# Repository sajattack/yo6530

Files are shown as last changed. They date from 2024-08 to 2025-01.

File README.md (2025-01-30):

yo6530 running a KIM-1 replica

build status (https://builds.sr.ht/~sajattack/yo6530?)

## Dependencies
- FPGA Toolchain: https://github.com/YosysHQ/oss-cad-suite-build
- Simulator: https://verilator.org/guide/latest/install.html
- C++ toolchain: gcc and gnu make
- Trace Viewer: https://gtkwave.sourceforge.net/
- SPI flash programmer: https://www.flashrom.org/
- Linter: https://github.com/chipsalliance/verible
- Hardware research in dwfpy directory uses a Digilent Digital Discovery, python and the dwfpy library to probe and stimulate a MOS6532, for understanding expected behaviour from real hardware

## Target Hardware
https://github.com/daglem/redip-riot

## Programming the board using Raspberry Pi (3B) with flashrom
### Wiring

| Raspi pin name/num  | ReDIP RIOT name/num|
| --- | ---|
| SCK / 23 | SPI_SCLK / 3 |
| MISO / 21 | SPI_SIO1 / 5 |
| MOSI / 19 | SPI_SIO0 / 7 |
| CE0 / 24 | SPI_CS / 1 |
| GPIO25 / 22 | CDONE / 2 |
| 3v3 / 17 | 3v3 / 8 |
| GND / 20 | GND / 6 |
| GPIO24 / 18 | CRESET / 4 |

```sh
make MCS6530_002=1 # build the project
scp build/mcs6530.bin pi@<your-pi's-ip>: # copy the build artifact to the pi for flashing
ssh pi@<your-pi's-ip> # connect to the pi
sudo raspi-config # go into the interfaces menu and enable spi after running this command
pinctrl set 24 op dl # put the board into programming mode by setting creset low
flashrom -p linux_spi:dev=/dev/spidev0.0,spispeed=20000 # if this detects the device, all is good, otherwise check your spi is enabled and your wiring
truncate -s 128K mcs6530.bin # pad the rom to 128K
flashrom -p linux_spi:dev=/dev/spidev0.0,spispeed=20000 -w mcs6530.bin # write the flash
pinctrl set 24 ip pu # exit programming mode by returning creset to input pullup
```

## Building and running the simulation tests
```sh
make MCS6530_002=1 sim
./obj_dir/Vverilator_top # this will throw assertion errors if the tests fail
```
Also you can examine the logic signals output during the test in the Vverilator_top.vcd file using [GTKWave](https://gtkwave.sourceforge.net/)

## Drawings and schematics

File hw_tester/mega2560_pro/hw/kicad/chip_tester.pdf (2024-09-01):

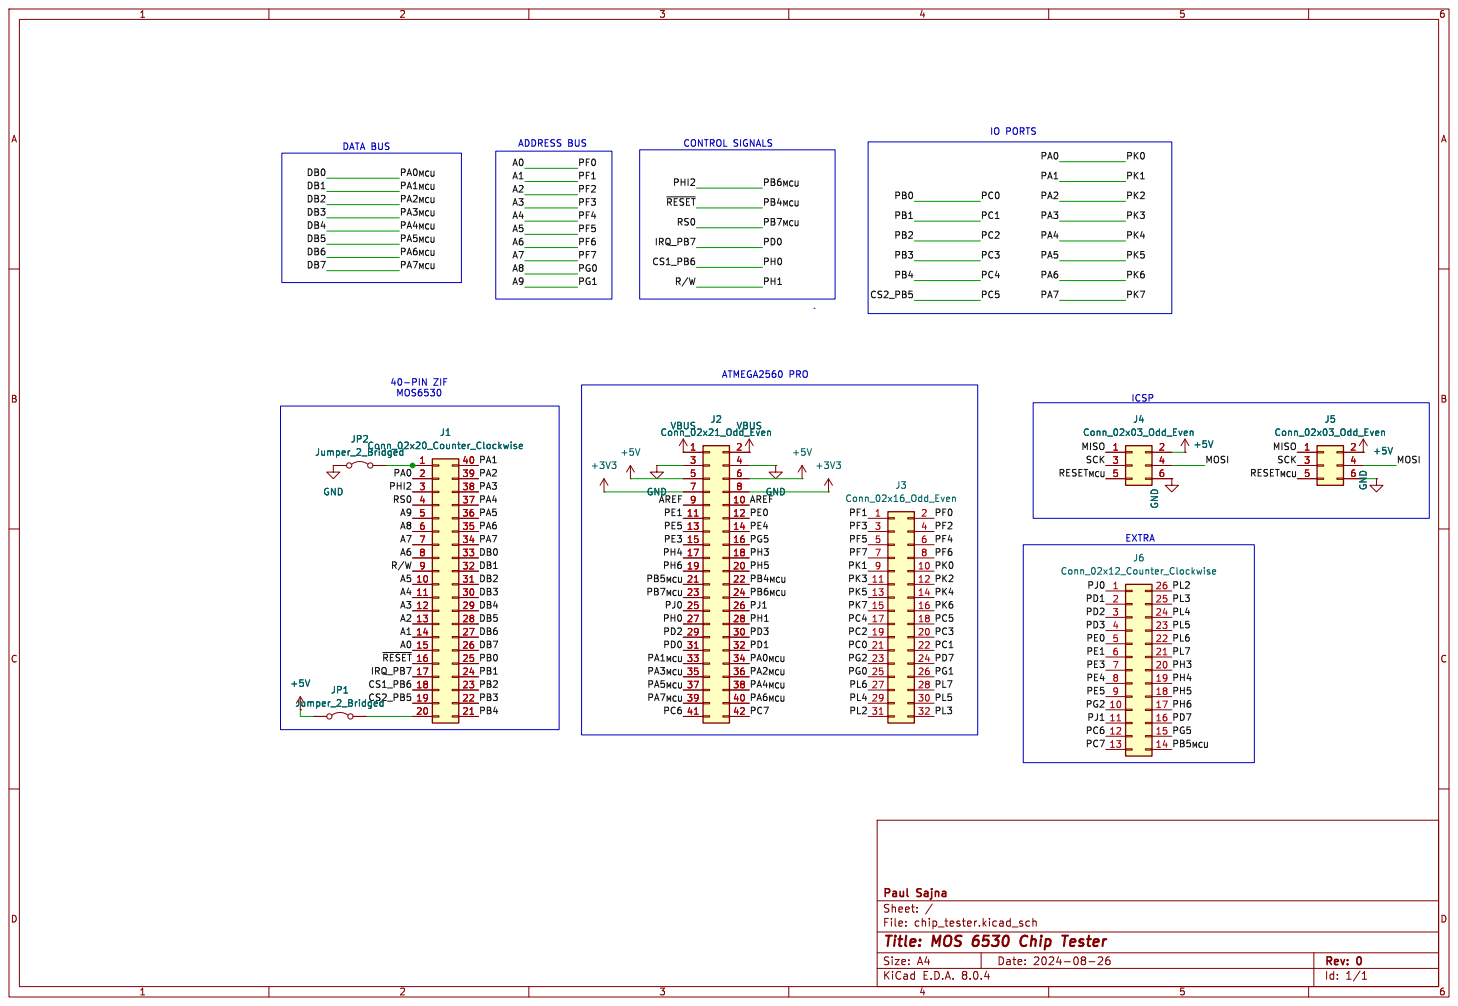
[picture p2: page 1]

IO PORTS CONTROL SIGNALS

Id: 1/1 Title: MOS 6530 Chip Tester File: chip_tester.kicad_sch Sheet: / Paul Sajna

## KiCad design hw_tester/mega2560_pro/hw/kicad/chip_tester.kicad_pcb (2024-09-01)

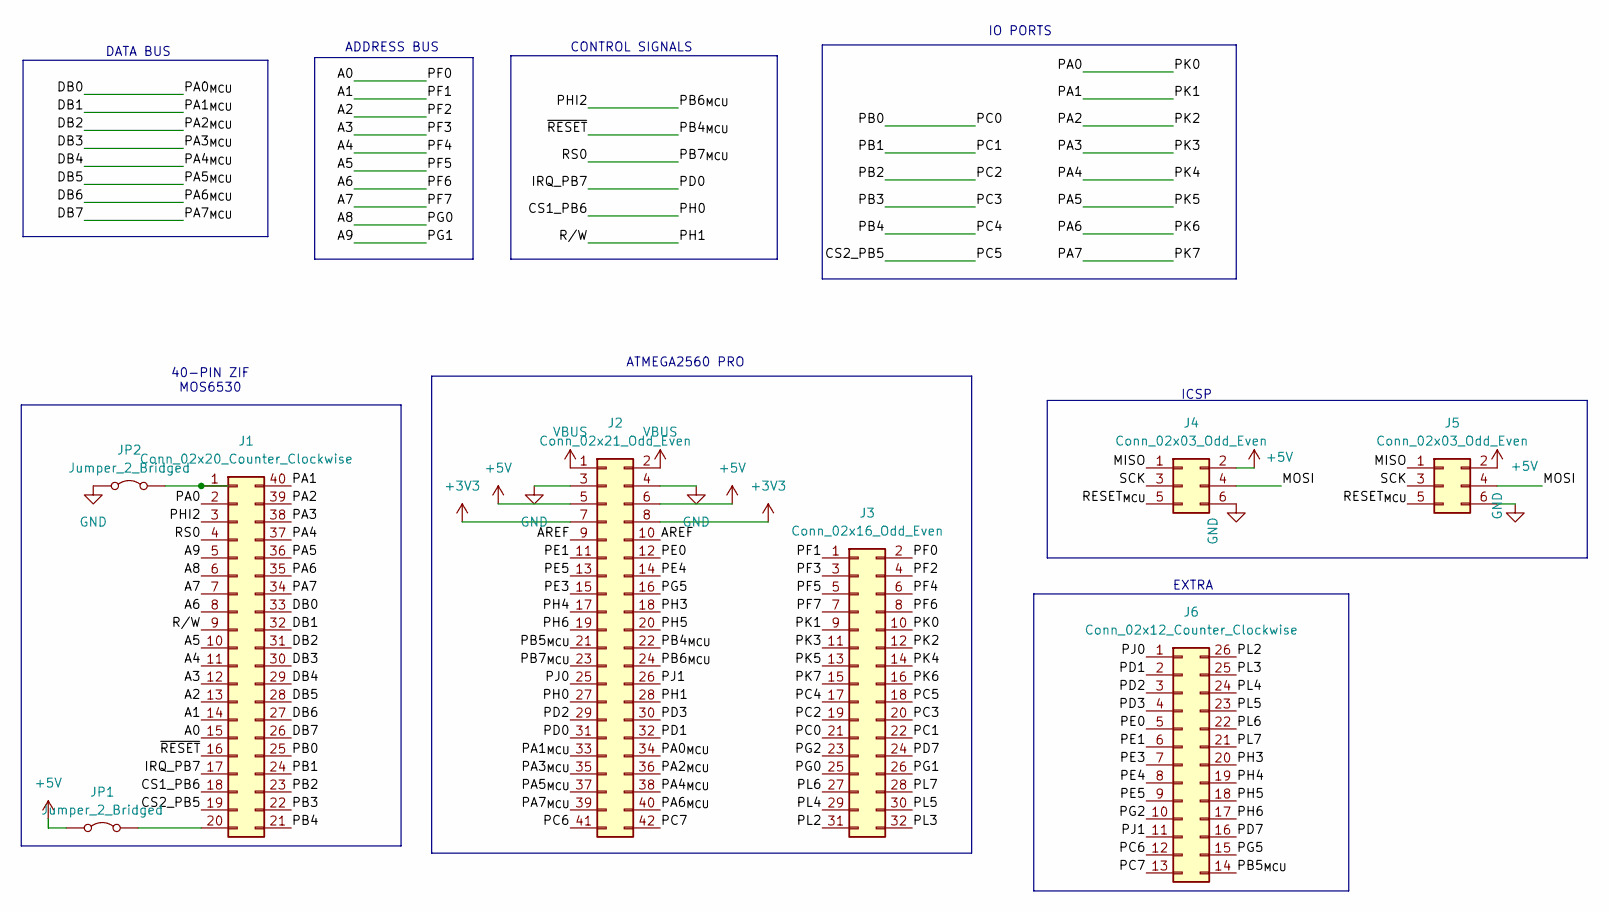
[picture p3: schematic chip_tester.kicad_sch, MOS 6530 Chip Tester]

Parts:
J1: Conn_02x20_Counter_Clockwise; 3M_Textool_240-1288-00-0602J_2x20_P2.54mm
J2: Conn_02x21_Odd_Even; PinHeader_2x21_P2.54mm_Vertical
J3: Conn_02x16_Odd_Even; PinHeader_2x16_P2.54mm_Vertical
J4, J5: Conn_02x03_Odd_Even; PinHeader_2x03_P2.54mm_Vertical
J6: Conn_02x12_Counter_Clockwise; PinHeader_2x13_P2.54mm_Vertical
JP1, JP2: Jumper_2_Bridged; SolderJumper-2_P1.3mm_Bridged_RoundedPad1.0x1.5mm

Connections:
+3V3: J2.7, J2.8
+5V: J2.5, J2.6, J4.2, J5.2, JP1.1 (A)
/A0: J1.15, J3.2
/A1: J1.14, J3.1
/A2: J1.13, J3.4
/A3: J1.12, J3.3
/A4: J1.11, J3.6
/A5: J1.10, J3.5
/A6: J1.8, J3.8
/A7: J1.7, J3.7
/A8: J1.6, J3.25
/A9: J1.5, J3.26
/AREF: J2.9, J2.10
/CS1_PB6: J1.18, J2.27
/CS2_PB5: J1.19, J3.18
/DB0: J1.33, J2.34
/DB1: J1.32, J2.33
/DB2: J1.31, J2.36
/DB3: J1.30, J2.35
/DB4: J1.29, J2.38
/DB5: J1.28, J2.37
/DB6: J1.27, J2.40
/DB7: J1.26, J2.39
/IRQ_PB7: J1.17, J2.31
/MISO: J4.1, J5.1
/MOSI: J4.4, J5.4
/PA0: J1.2, J3.10
/PA1: J1.40, J3.9
/PA2: J1.39, J3.12
/PA3: J1.38, J3.11
/PA4: J1.37, J3.14
/PA5: J1.36, J3.13
/PA6: J1.35, J3.16
/PA7: J1.34, J3.15
/PB0: J1.25, J3.21
/PB1: J1.24, J3.22
/PB2: J1.23, J3.19
/PB3: J1.22, J3.20
/PB4: J1.21, J3.17
/PB4_{MCU}: J1.16, J2.22
/PB5_{MCU}: J2.21, J6.14
/PB6_{MCU}: J1.3, J2.24
/PB7_{MCU}: J1.4, J2.23
/PC6: J2.41, J6.12
/PC7: J2.42, J6.13
/PD1: J2.32, J6.2
/PD2: J2.29, J6.3
/PD3: J2.30, J6.4
/PD7: J3.24, J6.16
/PE0: J2.12, J6.5
/PE1: J2.11, J6.6
/PE3: J2.15, J6.7
/PE4: J2.14, J6.8
/PE5: J2.13, J6.9
/PG2: J3.23, J6.10
/PG5: J2.16, J6.15
/PH1: J1.9, J2.28
/PH3: J2.18, J6.20
/PH4: J2.17, J6.19
/PH5: J2.20, J6.18
/PH6: J2.19, J6.17
/PJ0: J2.25, J6.1
/PJ1: J2.26, J6.11
/PL2: J3.31, J6.26
/PL3: J3.32, J6.25
/PL4: J3.29, J6.24
/PL5: J3.30, J6.23
/PL6: J3.27, J6.22
/PL7: J3.28, J6.21
/RESET_{MCU}: J4.5, J5.5
/SCK: J4.3, J5.3
GND: J2.3, J2.4, J4.6, J5.6, JP2.1 (A)
unnamed: J1.1, JP2.2 (B)
unnamed: J1.20, JP1.2 (B)
VBUS: J2.1, J2.2

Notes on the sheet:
ADDRESS BUS
IO PORTS
ICSP
40-PIN ZIF MOS6530
EXTRA
ATMEGA2560 PRO
DATA BUS
CONTROL SIGNALS

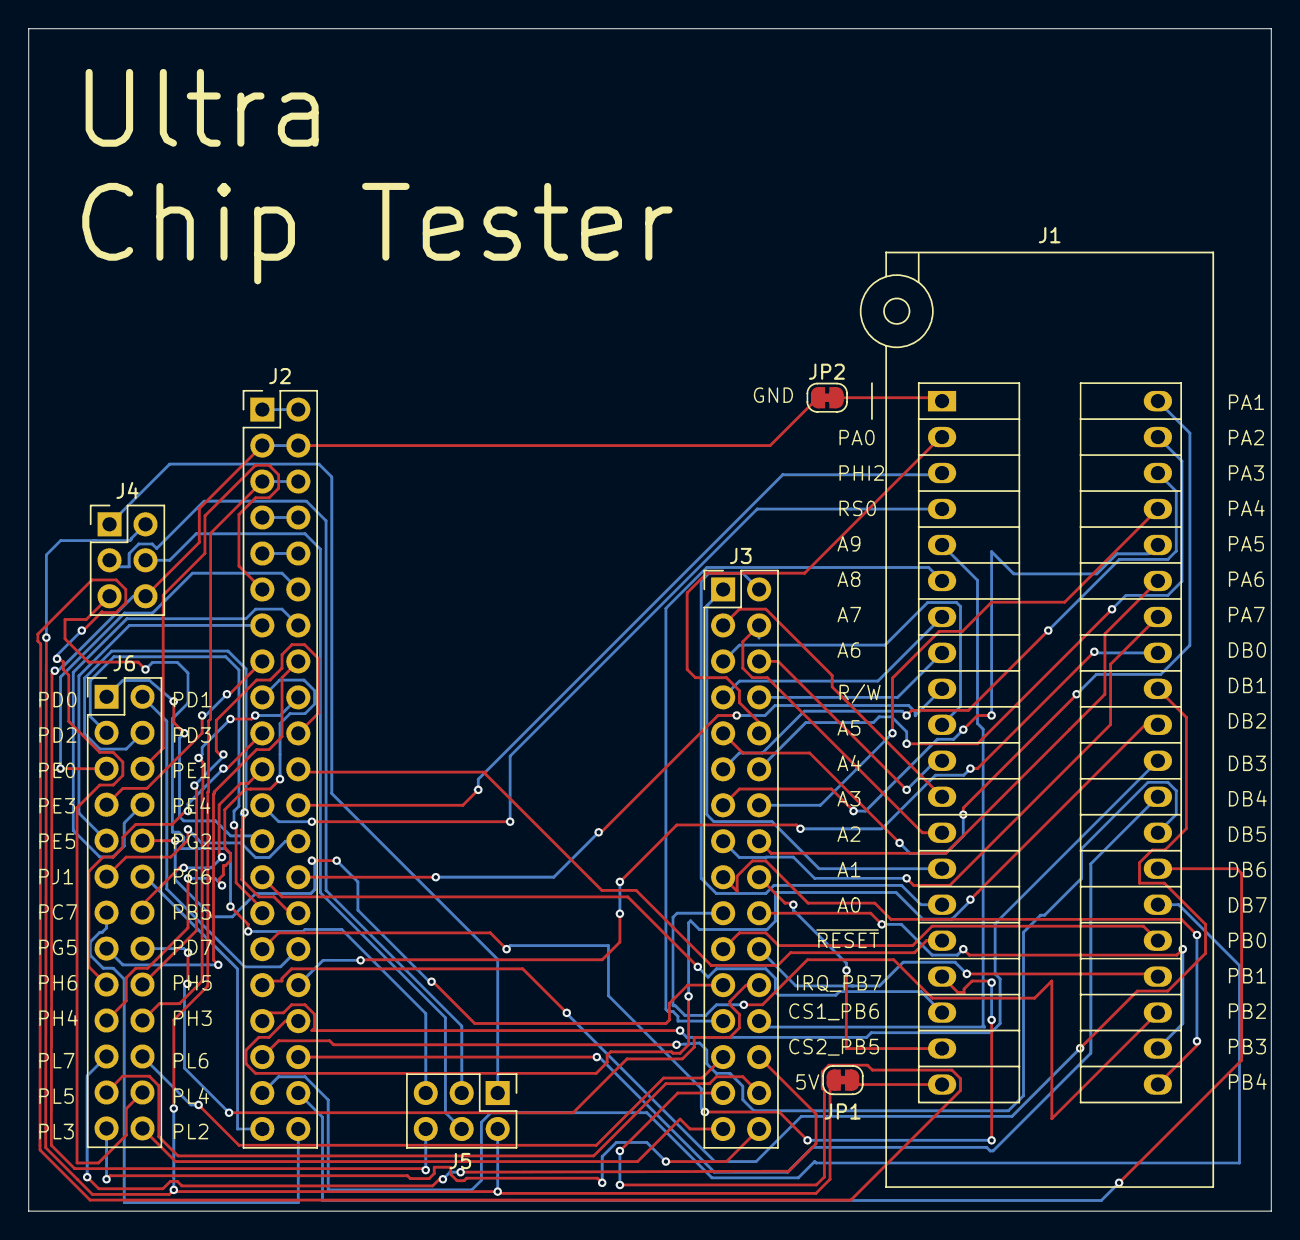
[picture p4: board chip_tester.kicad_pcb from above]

Board: 2 copper layers, 87.8 x 83.5 mm, 8 parts (0 on the bottom side), 75 nets.

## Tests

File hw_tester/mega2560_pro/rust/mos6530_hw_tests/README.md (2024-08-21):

mos6530_hw_tests
================

Rust project for the _Arduino Mega 2560_.

## Build Instructions
1. Install prerequisites as described in the [`avr-hal` README] (`avr-gcc`, `avr-libc`, `avrdude`, [`ravedude`]).

2. Run `cargo build` to build the firmware.

3. Run `cargo run` to flash the firmware to a connected board.  If `ravedude`
   fails to detect your board, check its documentation at
   <https://crates.io/crates/ravedude>.

4. `ravedude` will open a console session after flashing where you can interact
   with the UART console of your board.

[`avr-hal` README]: https://github.com/Rahix/avr-hal#readme
[`ravedude`]: https://crates.io/crates/ravedude

## License
Licensed under either of

 - Apache License, Version 2.0
   ([LICENSE-APACHE](LICENSE-APACHE) or <http://www.apache.org/licenses/LICENSE-2.0>)
 - MIT license
   ([LICENSE-MIT](LICENSE-MIT) or <http://opensource.org/licenses/MIT>)

at your option.

## Contribution
Unless you explicitly state otherwise, any contribution intentionally submitted
for inclusion in the work by you, as defined in the Apache-2.0 license, shall
be dual licensed as above, without any additional terms or conditions.

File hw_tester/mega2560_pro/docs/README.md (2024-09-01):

## Purchase Link
https://www.aliexpress.com/item/1005006102314234.html

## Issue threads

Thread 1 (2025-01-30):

Change ifdefs to verilog module parameters

sajattack, 2025-01-30:
It would be nicer for consumers of this module if we used verilog module parameters instead of defines. Like say someone wanted to make a kim-1 verilog module, they would need to create two wrapper files with different defines for the two different 6530s or something currently. Parameters would make this better.

sajattack, 2025-02-26:
resolved in 3a81e4ac4fda2156d2c24cc2ff9b66108605bdcd

Closed 2025-02-26.

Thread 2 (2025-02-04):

KIM-1 ROMs filler bytes

HansOtten, 2025-02-04:
Not that it will make any functional difference, but the ROM dumps of a real KIM-1 have 00 as filler bytes, not the FF as found in the ROMs generated from assembly source, as you have included here.

I have documented this here: http://retro.hansotten.nl/original-kim-1-roms-reproduced/

Hans

BTW Great work this replacement! Hope some one will sell reDIPs in the future.

sajattack, 2025-02-04:
I appreciate your interest Hans. Your website was very helpful to me during this project. I noticed this actually while I was working on my tester and comparing to real chips. I'll get it corrected. I have a small number of extra reDIP RRIOTs and I would be happy to sell you one or two. Send me an email if you're interested.

HansOtten, 2025-02-05:
Hi Paul,

Nice to hear from you. And breathing life in old damaged KIM-1s with 6530 replacements!

Yes, I love to have some reDIPs. Two would be fine to populate my Eduardo Casino (a good friend of mine, we had some fun recreating the KIM-1 PCB, brilliant work by him).

Let me know what the price is, an shipping cost, paypal is fine.

Greetings!

Hans Otten

Meester van Busselstraat 15

5731 NA Mierlo

The Netherlands

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

HansOtten, 2025-02-05:
Email sent!

Closed 2025-02-07.

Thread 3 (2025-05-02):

Asteroid seems to run too fast (timer issue)

sajattack, 2025-05-02:
Following game seems to instantly kill the player, indicating an issue with my timer code on the RRIOTs:
https://github.com/jefftranter/6502/tree/master/asm/KIM-1/TheFirstBookOfKIM/Games/Asteroid

See video for rough expected speed
https://www.youtube.com/watch?v=xQMCROH3mDc

Closed 2025-05-02.

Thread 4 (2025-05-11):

Improve naming conventions

sajattack, 2025-05-11:
- mixup of DDR/OE
- OE used for function select (use ie timer_select instead)
- maybe try to find a better name for we_n
- also try to fix the `// Data to processor` comments that are blatantly wrong

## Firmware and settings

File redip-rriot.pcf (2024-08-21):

# MOS 6530 RRIOT
# Pin Constraints File for iCE40UP5K-SG48

set_io -nowarn A0      18
set_io -nowarn A1      19
set_io -nowarn A2      20
set_io -nowarn A3      21
set_io -nowarn A4      23
set_io -nowarn A5      27
set_io -nowarn A6      25
set_io -nowarn A7      41
set_io -nowarn A8      40
set_io -nowarn A9      39
set_io -nowarn RS0     28

set_io -nowarn DB0     44
set_io -nowarn DB1     45
set_io -nowarn DB2     46
set_io -nowarn DB3      6
set_io -nowarn DB4      4
set_io -nowarn DB5      3
set_io -nowarn DB6      2
set_io -nowarn DB7     48

set_io -nowarn -pullup 1 -pullup_resistor 6P8K PA0     32
set_io -nowarn -pullup 1 -pullup_resistor 6P8K PA1     34
set_io -nowarn -pullup 1 -pullup_resistor 6P8K PA2     35
set_io -nowarn -pullup 1 -pullup_resistor 6P8K PA3     36
set_io -nowarn -pullup 1 -pullup_resistor 6P8K PA4     37
set_io -nowarn -pullup 1 -pullup_resistor 6P8K PA5     38
set_io -nowarn -pullup 1 -pullup_resistor 6P8K PA6     42
set_io -nowarn -pullup 1 -pullup_resistor 6P8K PA7     43

set_io -nowarn -pullup 1 -pullup_resistor 6P8K PB0     47
set_io -nowarn -pullup 1 -pullup_resistor 6P8K PB1      9
set_io -nowarn -pullup 1 -pullup_resistor 6P8K PB2     10
set_io -nowarn -pullup 1 -pullup_resistor 6P8K PB3     11
set_io -nowarn -pullup 1 -pullup_resistor 6P8K PB4     12
set_io -nowarn -pullup 1 -pullup_resistor 6P8K CS2_PB5 13
set_io -nowarn -pullup 1 -pullup_resistor 6P8K CS1_PB6 14
set_io -nowarn -pullup 1 -pullup_resistor 6P8K IRQ_PB7 15

set_io -nowarn PHI2    31
set_io -nowarn RES     17
set_io -nowarn R_W     26

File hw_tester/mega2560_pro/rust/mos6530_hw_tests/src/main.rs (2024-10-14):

#![no_std]
#![no_main]

#![feature(abi_avr_interrupt)]
#![feature(asm_experimental_arch)]
/// MOS 6530 Chip Tester
///
/// Data bus PA0-PA7
/// Addr bus PF0-PF7 + PG0-1
/// PHI2 PB6
/// RW PH1
/// RS0 PB7
/// RESET PB4
/// IRQ PD0
/// CS1 PH0
/// IO PORTS PC0-5 PK0-7

use panic_serial as _;

panic_serial::impl_panic_handler!(
  // This is the type of the UART port to use for printing the message:
  arduino_hal::usart::Usart<
    arduino_hal::pac::USART0,
    arduino_hal::port::Pin<arduino_hal::port::mode::Input, arduino_hal::hal::port::PE0>,
    arduino_hal::port::Pin<arduino_hal::port::mode::Output, arduino_hal::hal::port::PE1>
  >
);

extern crate alloc;

use alloc::vec::Vec;

use core::{time::Duration, convert::Infallible};

use arduino_hal::{
    Pins,
    Peripherals,
    pac::{
        PORTA,
        PORTB,
        PORTC,
        PORTK,
        PORTF,
        PORTH,
        PORTG,
        PORTD,
        TC1, USART0, EXINT,
        SPI,
    }, hal::{Usart, Atmega, port::{PE0, PE1}}, port::{Pin, mode::{Input, Output}}, clock::MHz16
};

use arduino_hal::hal::spi::{self, Spi, SpiOps};
use spi_flash::Flash;
use embedded_hal::{spi::SpiDevice, spi::SpiBus , digital::OutputPin};
use embedded_hal_bus::spi::ExclusiveDevice;

static ROM_002: [u8; 1024] = *include_bytes!("../../../../../roms/6530-002.bin");
static ROM_003: [u8; 1024] = *include_bytes!("../../../../../roms/6530-003.bin");

#[avr_device::interrupt(atmega2560)]
fn INT0() {
    //let dp = unsafe { arduino_hal::Peripherals::steal() };
    //let pins = arduino_hal::hal::pins!(dp);
    //let mut serial = arduino_hal::hal::usart::Usart0::new(dp.USART0, pins.pe0.into(), pins.pe1.into_output(), arduino_hal::usart::Baudrate::<arduino_hal::hal::clock::MHz16>::new(115200));
    //ufmt::uwriteln!(&mut serial, "INTERRUPT FIRED\r").unwrap();
}

#[arduino_hal::entry]
fn main() -> ! {
    let mut dp = arduino_hal::Peripherals::take().unwrap();
    let pins = arduino_hal::hal::pins!(dp);


    let mut serial = arduino_hal::hal::usart::Usart0::new(dp.USART0, pins.pe0.into(), pins.pe1.into_output(), arduino_hal::usart::Baudrate::<arduino_hal::hal::clock::MHz16>::new(115200));
    let mut serial = share_serial_port_with_panic(serial);

    let mut dp2 = unsafe { arduino_hal::Peripherals::steal() };


    let mut timer = dp2.TC1;
    let mut porta = dp2.PORTA;
    let mut portb = dp2.PORTB;
    let mut portk = dp2.PORTK;
    let mut portf = dp2.PORTF;
    let mut porth = dp2.PORTH;
    let mut portg = dp2.PORTG;
    let mut portd = dp2.PORTD;
    let mut exint = dp2.EXINT;

    // disable pull-ups
    //dp.CPU.mcucr.modify(|_, w| { w.pud().set_bit()});
    
    loop {
        ufmt::uwriteln!(serial, "Press 2 or 3 to test MOS6530-002 or MOS6530-003\r").unwrap();
        ufmt::uwriteln!(serial, "Press p to reprogram").unwrap();

        let input = serial.read_byte();

        start_1mhz_clock_out(&mut portb,  &mut timer);
        toggle_reset(&mut portb);

        if input == b'2' {
            test_rom_002(&mut porta, &mut portb, &mut portf, &mut portg, &mut porth, serial);
            test_ram_002(&mut porta, &mut portb, &mut portf, &mut portg, &mut porth, serial);
            test_io_002(&mut porta, &mut portb, &mut portf, &mut portg, &mut porth, &mut portk, serial);
            test_timer_002(&mut porta, &mut portb, &mut portf, &mut portg, &mut porth, &mut exint, serial);
        } 

        else if input == b'3' {
            test_rom_003(&mut porta, &mut portb, &mut portf, &mut portg, &mut porth, serial);
            test_ram_003(&mut porta, &mut portb, &mut portf, &mut portg, &mut porth, serial);
            test_io_003(&mut porta, &mut portb, &mut portf, &mut portg, &mut porth, &mut portk, serial);
            test_timer_003(&mut porta, &mut portb, &mut portf, &mut portg, &mut porth, &mut exint, serial);
        }

        else if input == b'p' {
            let dp3 = unsafe { arduino_hal::Peripherals::steal() };
            reprogram(dp3);
        }

        dp2 = unsafe { arduino_hal::Peripherals::steal() };

        let pins = arduino_hal::hal::pins!(dp2);
        serial = share_serial_port_with_panic(arduino_hal::hal::usart::Usart0::new(dp2.USART0, pins.pe0.into(), pins.pe1.into_output(), arduino_hal::usart::Baudrate::<arduino_hal::hal::clock::MHz16>::new(115200)));
        ufmt::uwriteln!(serial, "\r").unwrap();
    }
}

fn start_1mhz_clock_out(
    portb: &mut PORTB,
    timer: &mut TC1,
) {
    portb.ddrb.modify(|_, w| w.pb6().set_bit());
    
    timer.tccr1a.write(|w| {
        w.com1b().match_set();
        w.wgm1().bits(15)
    });
    timer.tccr1b.write(|w| {
        w.cs1().direct();
        w.wgm1().bits(15)
    });

    timer.ocr1a.write(|w| w.bits(15));
    timer.ocr1b.write(|w| w.bits(7));
}

fn toggle_reset( 
    portb: &mut PORTB,
) {
    portb.ddrb.modify(|_, w| w.pb4().set_bit());
    portb.portb.modify(|_, w| w.pb4().set_bit());
    arduino_hal::delay_us(1);
    portb.portb.modify(|_, w| w.pb4().clear_bit());
    arduino_hal::delay_us(1);
    portb.portb.modify(|_, w| w.pb4().set_bit());
}

fn test_rom_003(
    porta: &mut PORTA,
    portb: &mut PORTB,
    portf: &mut PORTF,
    portg: &mut PORTG,
    porth: &mut PORTH,
    serial: &mut Usart<USART0, Pin<Input, PE0>, Pin<Output, PE1>, MHz16>,
) {
    test_rom(porta, portb, portf, portg, porth, serial, &ROM_003);
}

fn test_rom_002(
    porta: &mut PORTA,
    portb: &mut PORTB,
    portf: &mut PORTF,
    portg: &mut PORTG,
    porth: &mut PORTH,
    serial: &mut Usart<USART0, Pin<Input, PE0>, Pin<Output, PE1>, MHz16>,
) {
    test_rom(porta, portb, portf, portg, porth, serial, &ROM_002);
}

fn test_ram_003(
    porta: &mut PORTA,
    portb: &mut PORTB,
    portf: &mut PORTF,
    portg: &mut PORTG,
    porth: &mut PORTH,
    serial: &mut Usart<USART0, Pin<Input, PE0>, Pin<Output, PE1>, MHz16>,
) {
    test_ram(porta, portb, portf, portg, porth, serial, 0x380);
}

fn test_ram_002(
    porta: &mut PORTA,
    portb: &mut PORTB,
    portf: &mut PORTF,
    portg: &mut PORTG,
    porth: &mut PORTH,
    serial: &mut Usart<USART0, Pin<Input, PE0>, Pin<Output, PE1>, MHz16>,
) {
    test_ram(porta, portb, portf, portg, porth, serial, 0x3c0);
}

fn test_io_003(
    porta: &mut PORTA,
    portb: &mut PORTB,
    portf: &mut PORTF,
    portg: &mut PORTG,
    porth: &mut PORTH,
    portk: &mut PORTK,
    serial: &mut Usart<USART0, Pin<Input, PE0>, Pin<Output, PE1>, MHz16>,
) {
    test_io(porta, portb, portf, portg, porth, portk, serial, 0x300);
}

fn test_io_002(
    porta: &mut PORTA,
    portb: &mut PORTB,
    portf: &mut PORTF,
    portg: &mut PORTG,
    porth: &mut PORTH,
    portk: &mut PORTK,
    serial: &mut Usart<USART0, Pin<Input, PE0>, Pin<Output, PE1>, MHz16>,
) {
    test_io(porta, portb, portf, portg, porth, portk, serial, 0x340);
}

fn test_timer_003(
    porta: &mut PORTA,
    portb: &mut PORTB,
    portf: &mut PORTF,
    portg: &mut PORTG,
    porth: &mut PORTH,
    exint: &mut EXINT,
    serial: &mut Usart<USART0, Pin<Input, PE0>, Pin<Output, PE1>, MHz16>,
) {
    test_timer(porta, portb, portf, portg, porth, exint, serial, 0x300);
}

fn test_timer_002(
    porta: &mut PORTA,
    portb: &mut PORTB,
    portf: &mut PORTF,
    portg: &mut PORTG,
    porth: &mut PORTH,
    exint: &mut EXINT,
    serial: &mut Usart<USART0, Pin<Input, PE0>, Pin<Output, PE1>, MHz16>,
) {
    test_timer(porta, portb, portf, portg, porth, exint, serial, 0x340);
}

fn test_rom(
    porta: &mut PORTA,
    portb: &mut PORTB,
    portf: &mut PORTF,
    portg: &mut PORTG,
    porth: &mut PORTH,
    serial: &mut Usart<USART0, Pin<Input, PE0>, Pin<Output, PE1>, MHz16>,
    rom: &'static [u8],
) {

    portb.ddrb.modify(|_, w| {
        w.pb7().set_bit() // RS0
    });
    porth.ddrh.modify(|_, w| {
        w.ph0().set_bit() // CS1
    });

    portb.portb.modify(|_, w| {
        w.pb7().clear_bit() // RS0
    });
    porth.porth.modify(|_, w| {
        w.ph0().set_bit()  // CS1
    });

    ufmt::uwriteln!(serial, "ROM read start\r").unwrap();
    let mut error_count = 0;
    for addr in 0..rom.len() {
        let byte_read = bus_read(porta, portf, portg, porth, addr as u16);
        let byte_expected = rom[addr];

        if byte_read != byte_expected {
            ufmt::uwriteln!(serial, "ROM read mismatch. Expected 0x{:02X} Got 0x{:02X}\r", byte_expected, byte_read).unwrap();
            error_count += 1;
        }
    }
    ufmt::uwriteln!(serial, "Error count: {}\r", error_count).unwrap();
    ufmt::uwriteln!(serial, "Finished rom test.\r").unwrap();
}

fn test_ram(
    porta: &mut PORTA,
    portb: &mut PORTB,
    portf: &mut PORTF,
    portg: &mut PORTG,
    porth: &mut PORTH,
    serial: &mut Usart<USART0, Pin<Input, PE0>, Pin<Output, PE1>, MHz16>,
    base_addr: u16,
) {
    
    portb.ddrb.modify(|_, w| {
        w.pb7().set_bit() // RS0
    });
    porth.ddrh.modify(|_, w| {
        w.ph0().set_bit() // CS1
    });

    portb.portb.modify(|_, w| {
        w.pb7().set_bit() // RS0
    });
    porth.porth.modify(|_, w| {
        w.ph0().clear_bit()  // CS1
    });

    let bytes = [0xAA, 0x55, 0xAA, 0x55, b'H', b'E', b'L', b'L', b'O', b'W', b'O', b'R', b'L', b'D', b'!'];

    ufmt::uwriteln!(serial, "RAM write start\r").unwrap();

    for addr in base_addr..base_addr + (bytes.len() as u16) {
        bus_write(porta, portf, portg, porth, addr as u16, bytes[(addr-base_addr) as usize]);
    }

    ufmt::uwriteln!(serial, "RAM read start\r").unwrap();

    let mut error_count = 0;
    for addr in base_addr..base_addr + (bytes.len() as u16) {
        let byte_read = bus_read(porta, portf, portg, porth, addr as u16);
        let byte_expected = bytes[(addr-base_addr) as usize];

        if byte_read != byte_expected {
            ufmt::uwriteln!(serial, "RAM read mismatch. Expected 0x{:02X} Got 0x{:02X}\r", byte_expected, byte_read).unwrap();
            error_count += 1;
        }
    }
    ufmt::uwriteln!(serial, "Error count: {}\r", error_count).unwrap();
    ufmt::uwriteln!(serial, "Finished ram test.\r").unwrap();

}

fn test_io(
    porta: &mut PORTA,
    portb: &mut PORTB,
    portf: &mut PORTF,
    portg: &mut PORTG,
    porth: &mut PORTH,
    portk: &mut PORTK,
    serial: &mut Usart<USART0, Pin<Input, PE0>, Pin<Output, PE1>, MHz16>,
    base_addr: u16,
) {
    portb.ddrb.modify(|_, w| {
        w.pb7().set_bit() // RS0
    });
    porth.ddrh.modify(|_, w| {
        w.ph0().set_bit() // CS1
    });

    portb.portb.modify(|_, w| {
        w.pb7().set_bit() // RS0
    });
    porth.porth.modify(|_, w| {
        w.ph0().clear_bit()  // CS1
    });

    ufmt::uwriteln!(serial, "Begin IO test\r").unwrap();
    // write RRIOT DDRA
    let addr = base_addr+1;
    let data = 0xff;
    bus_write(porta, portf, portg, porth, addr, data);

    // write RRIOT IO
    let addr = base_addr;
    let data = 0x55;
    bus_write(porta, portf, portg, porth, addr, data);
    
    // check output on PORTA (PK on the mega2560);
    portk.ddrk.write(|w| {
        w.pk0().clear_bit();
        w.pk1().clear_bit();
        w.pk2().clear_bit();
        w.pk3().clear_bit();
        w.pk4().clear_bit();
        w.pk5().clear_bit();
        w.pk6().clear_bit();
        w.pk7().clear_bit()
    });
    let porta_out = portk.pink.read().bits();
    if porta_out == data {
        ufmt::uwriteln!(serial, "Successfully output 0x{:02X} on PORTA\r", data).unwrap();
    }
    else {
        ufmt::uwriteln!(serial, "Output mismatch on PORTA, expected 0x{:02X}, got 0x{:02X}\r", data, porta_out).unwrap();
    }
    ufmt::uwriteln!(serial, "Finished IO test\r").unwrap(); 
}

fn test_timer(
    porta: &mut PORTA,
    portb: &mut PORTB,
    portf: &mut PORTF,
    portg: &mut PORTG,
    porth: &mut PORTH,
    exint: &mut EXINT,
    serial: &mut Usart<USART0, Pin<Input, PE0>, Pin<Output, PE1>, MHz16>,
    base_addr: u16
) {

    portb.ddrb.modify(|_, w| {
        w.pb7().set_bit() // RS0
    });
    porth.ddrh.modify(|_, w| {
        w.ph0().set_bit() // CS1
    });

    portb.portb.modify(|_, w| {
        w.pb7().set_bit() // RS0
    });
    porth.porth.modify(|_, w| {
        w.ph0().clear_bit()  // CS1
    });

    unsafe { avr_device::interrupt::enable() }; 

    // enable INT0 falling edge interrupt
    exint.eicra.modify(|_, w| { w.isc0().val_0x02()});
    exint.eimsk.modify(|_, w| { w.int().bits(1)});

    ufmt::uwriteln!(serial, "Timer write start\r").unwrap();
    let addr = base_addr + 0xf;
    bus_write(porta, portf, portg, porth, addr, 0);

    ufmt::uwriteln!(serial, "Timer read start\r").unwrap();
    let addr = base_addr + 0xe;

    let timer_val = bus_read(porta, portf, portg, porth, addr);
    ufmt::uwriteln!(serial, "Timer value: {}\r", timer_val).unwrap();

    ufmt::uwriteln!(serial, "Timer read end\r").unwrap();
}

fn write_data(porta: &mut PORTA, data: u8) {
    porta.ddra.write(|w| {
        w.pa0().set_bit();
        w.pa1().set_bit();
        w.pa2().set_bit();
        w.pa3().set_bit();
        w.pa4().set_bit();
        w.pa5().set_bit();
        w.pa6().set_bit();
        w.pa7().set_bit()
    });
    porta.porta.write(|w| {
        unsafe { w.bits(data) }
    });
}

fn read_data(porta: &mut PORTA) -> u8 {
    porta.ddra.write(|w| {
        w.pa0().clear_bit();
        w.pa1().clear_bit();
        w.pa2().clear_bit();
        w.pa3().clear_bit();
        w.pa4().clear_bit();
        w.pa5().clear_bit();
        w.pa6().clear_bit();
        w.pa7().clear_bit()
    });
    porta.pina.read().bits()
}

fn write_addr(portf: &mut PORTF, portg: &mut PORTG, addr: u16) {
    portf.ddrf.write(|w| {
        w.pf0().set_bit();
        w.pf1().set_bit();
        w.pf2().set_bit();
        w.pf3().set_bit();
        w.pf4().set_bit();
        w.pf5().set_bit();
        w.pf6().set_bit();
        w.pf7().set_bit()
    });

    portg.ddrg.modify(|_, w| {
        w.pg0().set_bit();
        w.pg1().set_bit()
    });

    portf.portf.write(|w| {
        unsafe { 
            w.bits(addr as u8)
        }
    });

    portg.portg.modify(|_, w| {
        w.pg0().bit(addr & 0b0100000000 > 0);
        w.pg1().bit(addr & 0b1000000000 > 0)
    });
}

fn bus_write(
    porta: &mut PORTA,
    portf: &mut PORTF,
    portg: &mut PORTG,
    porth: &mut PORTH,
    addr: u16,
    data: u8
) {


    // rw is ph1
    porth.ddrh.modify(|_, w| {
        w.ph1().set_bit()
    });
    porth.porth.modify(|_, w| {
        w.ph1().clear_bit()
    });

    write_addr(portf, portg, addr);

    arduino_hal::delay_us(1);

    write_data(porta, data);

    arduino_hal::delay_us(1);

    // rw is ph1
    // deassert
    porth.porth.modify(|_, w| {
        w.ph1().set_bit()
    });
    porth.ddrh.modify(|_, w| {
        w.ph1().clear_bit()
    });


    // deassert data bus
    porta.ddra.write(|w| {
        w.pa0().clear_bit();
        w.pa1().clear_bit();
        w.pa2().clear_bit();
        w.pa3().clear_bit();
        w.pa4().clear_bit();
        w.pa5().clear_bit();
        w.pa6().clear_bit();
        w.pa7().clear_bit()
    });
}

fn bus_read(
    porta: &mut PORTA,
    portf: &mut PORTF,
    portg: &mut PORTG,
    porth: &mut PORTH,
    addr: u16,
) -> u8 {

    // rw is ph1
    porth.ddrh.modify(|_, w| {
        w.ph1().set_bit()
    });
    porth.porth.modify(|_, w| {
        w.ph1().set_bit()
    });

    write_addr(portf, portg, addr);

    arduino_hal::delay_us(1);

    read_data(porta)
}

fn reprogram(
    dp: Peripherals,  
) {
    let pins = arduino_hal::pins!(dp);
    let (spi, cs) = Spi::new(dp.SPI, pins.d52.into_output(), pins.d51.into_output(), pins.d50.into_pull_up_input(), pins.d53.into_output(), spi::Settings::default());
    let mut spi = ExclusiveDevice::new(spi, cs, arduino_hal::Delay::new()).unwrap();
    let mut spi = spi.bus_mut();
    let mut serial = arduino_hal::hal::usart::Usart0::new(dp.USART0, pins.d0.into_pull_up_input(), pins.d1.into_output(), arduino_hal::usart::Baudrate::<arduino_hal::hal::clock::MHz16>::new(115200));
    let mut interface = SpiFlashInterface::new(spi);
    let mut spi_flash = Flash::new(&mut interface);
    let result = spi_flash.erase();
    if result.is_err() {
        ufmt::uwriteln!(&mut serial, "Flash Erase Error\r");
    } else {
        ufmt::uwriteln!(&mut serial, "Flash Erase Success\r");
    }
    let result = spi_flash.program(0, &[0x55; 1], true);
    if result.is_err() {
        ufmt::uwriteln!(&mut serial, "Flash Verify Error\r");
    } else {
        ufmt::uwriteln!(&mut serial, "Flash Verify Success\r");
    }
}

use buddy_alloc::{BuddyAllocParam, FastAllocParam, NonThreadsafeAlloc};

const FAST_HEAP_SIZE: usize = 64; 
const HEAP_SIZE: usize = 1024;

pub static mut FAST_HEAP: [u8; FAST_HEAP_SIZE] = [0u8; FAST_HEAP_SIZE];
pub static mut HEAP: [u8; HEAP_SIZE] = [0u8; HEAP_SIZE];

// This allocator can't work in tests since it's non-threadsafe.
#[cfg_attr(not(test), global_allocator)]
static ALLOC: NonThreadsafeAlloc = unsafe {
    let fast_param = FastAllocParam::new(FAST_HEAP.as_ptr(), FAST_HEAP_SIZE);
    let buddy_param = BuddyAllocParam::new(HEAP.as_ptr(), HEAP_SIZE, 16);
    NonThreadsafeAlloc::new(fast_param, buddy_param)
};

struct SpiFlashInterface<'a> {
    spi: &'a mut Spi,
}

impl<'a> SpiFlashInterface<'a> {
    fn new(spi: &'a mut Spi) -> Self {
        Self {
            spi
        }
    }
}

impl<'a> spi_flash::FlashAccess for SpiFlashInterface<'a> {
    type Error = spi_flash::Error;

    fn exchange(&mut self, data: &[u8]) -> Result<Vec<u8>, Self::Error> 
    {
        let mut read_vec = Vec::new();
        read_vec.resize(8, 0);
        let result = self.spi.transfer(read_vec.as_mut(), data);
        match result {
            Ok(()) => Ok(read_vec),
            Err(_e) => Err(spi_flash::Error::Access)
        }
    }

    fn write(&mut self, data: &[u8]) -> Result<(), Self::Error> {
        let _ = self.spi.write(data);
        Ok(())
    }

    fn delay(&mut self, duration: Duration) {
        // this has pretty horrible accuracy but yolo
        if duration.as_micros() < 1000 
        {
            arduino_hal::delay_us(duration.as_micros() as u32);
        }
        else {
            arduino_hal::delay_ms(duration.as_millis() as u16);
        }
    }
}

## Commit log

2023-11-13 timer test rom, new pcf, top file, makefile tweaks
2024-01-17 timer test & fix some address decoding bugs
2024-01-22 start working on cycle timing accuracy
    NOTE: once the clock cycles were reduced the timer code started
    failing assertions. TODO.
    [c64_bus_timing.csv]
2024-01-24 fix the timer
2024-02-11 fix timer sim
2024-02-14 disable timer_irq until I understand it better
2024-08-05 switch to 6530-002
2024-09-01 chip tester pcb
    [chip_tester-B_Cu.gbr, chip_tester-B_Mask.gbr, chip_tester-B_Paste.gbr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]
2024-09-01 minor board layout changes
    [chip_tester-B_Cu.gbr, chip_tester-B_Mask.gbr, chip_tester-B_Paste.gbr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]
2024-09-13 minor timer changes
2024-09-13 fix timer validation
2024-09-18 some random stuff I didn't commit before
    [main.rs]
2024-10-01 io is broken trying to fix
    [main.rs]
2024-10-05 switch pintype and use negedge of clock, also change timer tests
2024-10-10 trying to add a spi flash programmer to the tester
2025-01-30 build both variants currently supported
2025-05-02 fix timer issue with Asteroid game (Fixes #3)
2026-07-19 Fix timer to match 6530 datasheet semantics; PB6/PB7 pin fixes
    Timer (src/timer.v), verified against the datasheet in
    reference/mos_6530_rriot.pdf pages 9-10:
    - A write no longer loses to a same-edge prescaler decrement. In /1
    mode (the reset default) the decrement fired every clock, so every
    timer write was silently discarded and the counter kept free-running.
    - The prescaler restarts on a timer write, so the first tick is a full
    divider period instead of leftover phase from the previous setting.
    - The interrupt flag is now separate from the /IRQ pin level. Enabling
    IRQ via A3 no longer asserts /IRQ immediately, the flag register reads
    0x80 after timeout in IRQ-enabled mode, an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
2026-07-19 Never drive the data bus on ROM-space write cycles
    rom_enable ignored R/W, so an (erroneous) write to ROM address space made
    the FPGA drive DB against the CPU's write data -- a bus fight the real
    6530 cannot produce, since its DB drivers are enabled only on reads.
    Gate rom_enable with we_n; the ROM has no write side, so nothing else
    changes.
2026-07-19 Drive the data bus only while PHI2 is high
    The data-bus output enable was raw address decode, so on read cycles the
    FPGA started driving DB during PHI1 (as soon as the address decoded) and
    kept driving briefly into the next cycle's PHI1 -- overlapping the bus
    turnaround window where a CPU or another device may still hold the bus.
    Harmless on a lone KIM-1, but this module will meet expansion buses and
    hardware we cannot test against.
    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
2026-07-21 timer is unaffected by reset, outside of irq_en
